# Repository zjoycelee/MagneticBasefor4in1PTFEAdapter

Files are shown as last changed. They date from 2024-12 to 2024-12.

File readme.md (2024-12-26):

# Bambulab 4-in-1 Adapter Holder with Magnetic Mount

This project provides 3D models for a **Bambulab 4-in-1 Adapter Holder** designed for easy attachment to the backplate of the **Bambu P1S/X1 3D printers**. The holder uses magnets for quick attachment and detachment, offering flexibility to easily move and adjust the adapter.

## Features

- **Magnetic Mount**: The holder uses magnets to attach securely to the backplate of the Bambu P1S/X1 3D printers.
- **Easy to Move and Adjust**: The magnetic attachment allows for simple repositioning of the adapter holder without the need for additional tools.
- **Space-saving**: The holder ensures the 4-in-1 adapter stays close to the backplate, minimizing clutter and maximizing space on your 3D printer.

## Advantages

- **Flexible Adjustment**: The magnetic mount makes it easy to reposition the adapter holder, giving you full control over the placement and ensuring it fits your workspace perfectly.
- **Convenient Movement**: Unlike fixed mounts, this solution allows you to move the adapter holder quickly and easily, without the hassle of screws or complicated installations.
- **Close Fit to the Backplate**: The design ensures that the adapter holder stays as close as possible to the backplate, optimizing space while maintaining a secure fit.

## Material Recommendation

Since the snap-fit is oriented along the Z-axis, it is recommended to use at least PETG material for 3D printing. Otherwise, the snap-fit may lack sufficient strength and may break easily. Based on testing, the following materials have been evaluated:

- [x] **Jayo PETG**: Suitable, with good strength; no issues with snap-fit durability.
- [ ] **Caige PLA**: Not suitable, with insufficient strength; prone to breaking.

## Folder Structure

This repository includes the following folder structure:

```bash
Copy code
assets/            # Folder for images (e.g., preview, magnet application)
stls/              # Folder for 3D model STL files
3mf/               # Folder for 3MF files
readme.md          # This README file
readme.zh.md       # readme in Chinese
.gitignore         # Git ignore file
```

## 3D Models

- The project includes 3D models for printing the adapter holder with a magnetic mount.
- You can find the **STL** and **3MF** files in the `stls/` and `3mf/` directories respectively.
- The holder is designed for easy integration with **Bambulab 4-in-1 Adapter**.

## Images

### Preview of the Adapter Holder
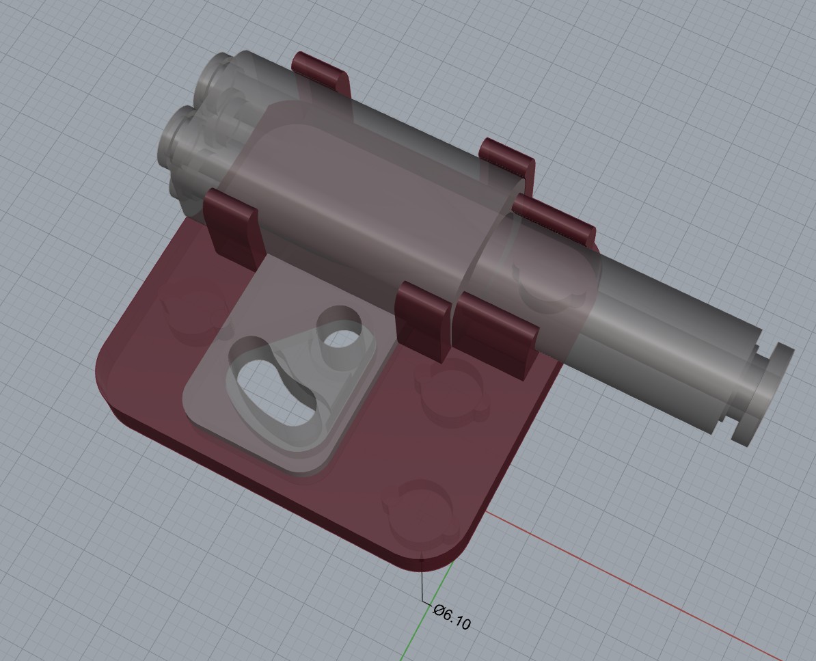
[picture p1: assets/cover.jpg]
Adapter Holder Preview

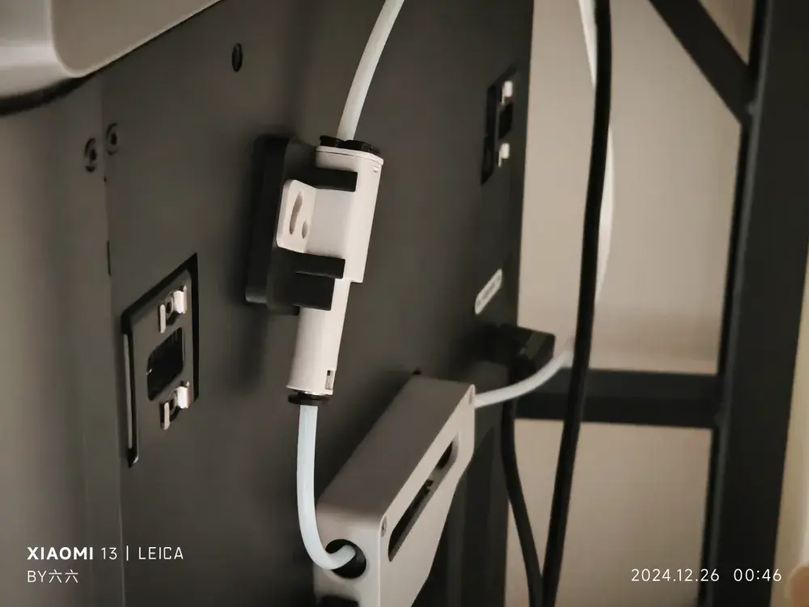
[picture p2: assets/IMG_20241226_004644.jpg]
live shot 1

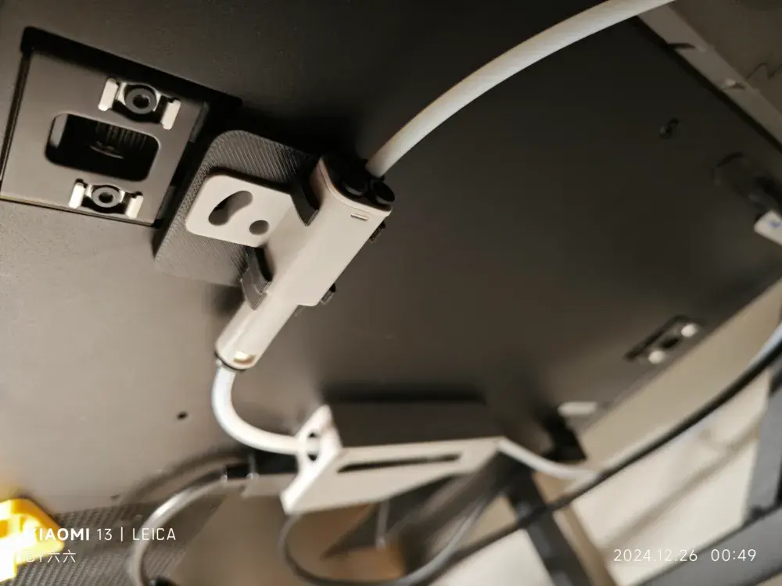
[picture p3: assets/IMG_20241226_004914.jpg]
live shot 2


Here is a preview of the **Bambulab 4-in-1 Adapter Holder** that you can print and use with your Bambu P1S/X1 3D printer.

### Magnet Application
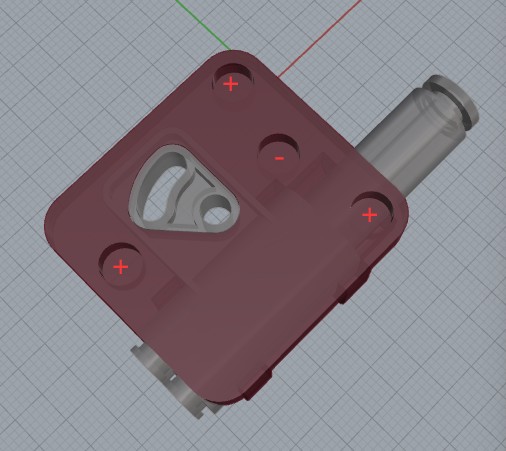
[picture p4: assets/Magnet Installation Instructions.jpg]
Magnet Application Introduction


This image demonstrates how to install the magnets to ensure the adapter holder is securely attached to the backplate of the Bambu P1S/X1 printer.

The hole size is D = 6.1mm and H = 3.4mm, while the magnet size is D = 6mm and H = 3mm. To ensure proper installation, the magnet should be aligned with the iron piece and pushed into the hole, ensuring that the surface of the magnet is flush with the surface of the model. This approach prevents the magnet from sinking too deep into the hole, which could lead to misalignment or improper magnetic performance.

## Assembly Instructions

1. **Print the Holder**: Download the 3D model files from the repository and print them using your 3D printer.
2. **Attach the Magnets**: Insert the magnets (D=6mm, H=3mm) into the designated holes on the holder.
3. **Mount on the Backplate**: Attach the magnetic holder to the backplate of your Bambu P1S/X1 printer. The magnets will hold the adapter securely in place.
4. **Adjust and Move**: You can now easily move and adjust the position of the adapter holder on the backplate for optimal space management.

## License

This project is licensed under the [Creative Commons Attribution 4.0 International License](https://creativecommons.org/licenses/by/4.0/).

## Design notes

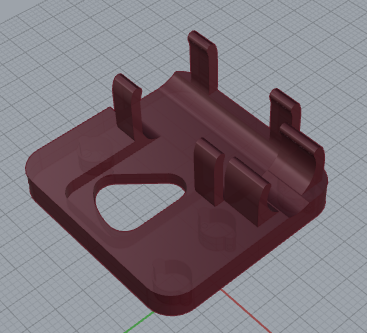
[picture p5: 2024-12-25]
assets/preview.png

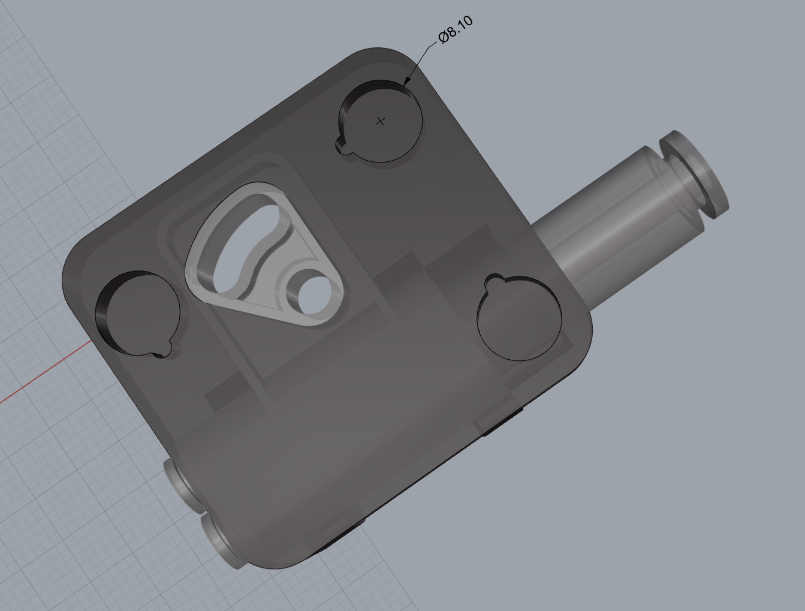
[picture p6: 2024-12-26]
assets/D8.1-H3.4.png

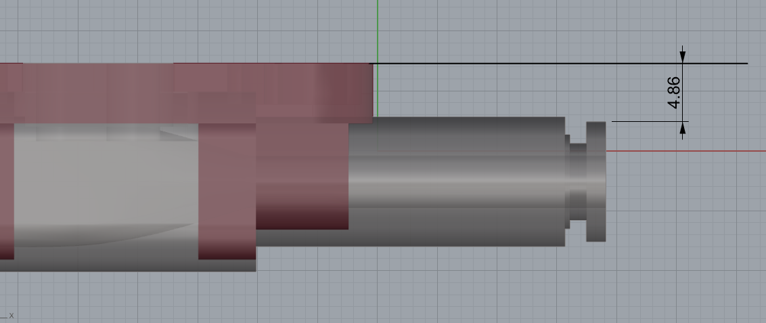
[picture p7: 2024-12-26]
assets/distance-introduction.png

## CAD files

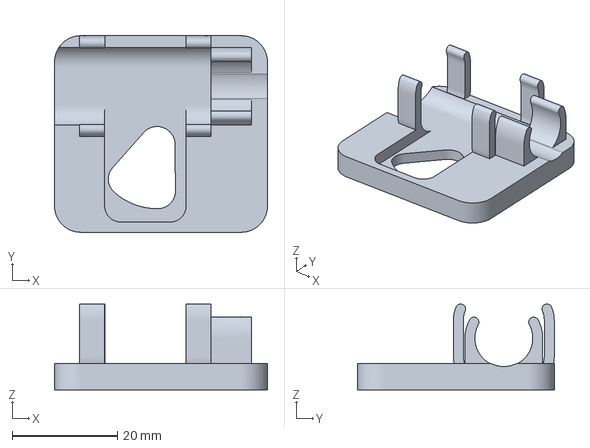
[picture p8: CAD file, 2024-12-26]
3mf/4-in-1-Adapter-Magnet-Holder(D8.1_H3.4).3mf
40.5 x 37.4 x 16.4 mm

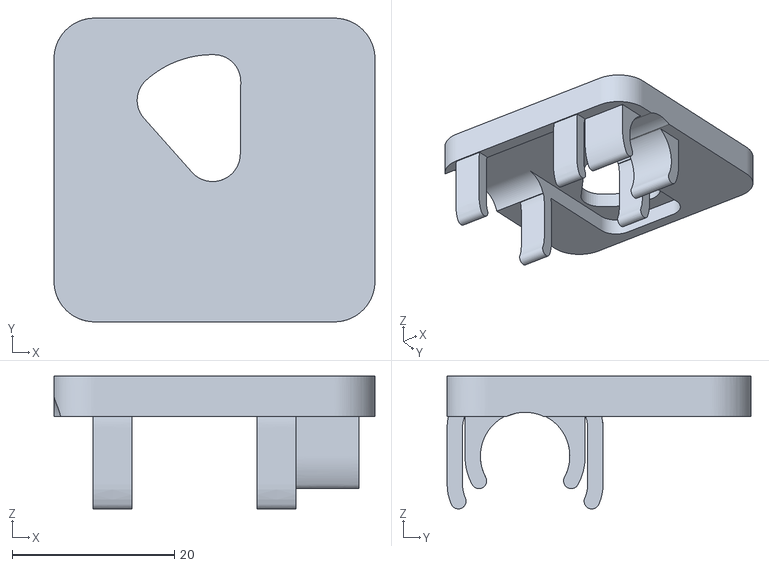
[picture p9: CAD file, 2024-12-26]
stls/withoutMagnetHoles.stl
39.5 x 37.4 x 16.4

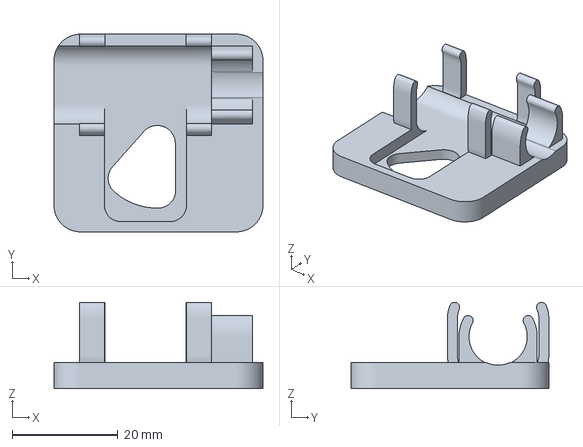
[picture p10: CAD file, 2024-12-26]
3mf/4-in-1-Adapter-Magnet-Holder(D6.1H3.4).3mf
39.5 x 37.4 x 16.4 mm

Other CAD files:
stls/D8.1H3.4.stl
stls/D6.1H3.4.stl

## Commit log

2024-12-25 add a holder(v2)
    [v2.stl]
2024-12-25 make circle bigger, d=2mm
    [v2.stl]
2024-12-25 add 3mf file
    [4-in-1-Adapter-Magnet-Holder.3mf]
2024-12-26 Add a new specification, D=8.1mm,H=3.4mm
    [D8.1H3.4.stl]
2024-12-26 chore: construct folder structure
    [D6.1H3.4.stl, D8.1H3.4.stl]
2024-12-26 feat: add 3mf file for D8H3.4 specification
    [4-in-1-Adapter-Magnet-Holder(D6.1H3.4).3mf, 4-in-1-Adapter-Magnet-Holder(D8.1_H3.4).3mf, 4-in-1-Adapter-Magnet-Holder.3mf]
2024-12-26 docs: update magnet application introduction
2024-12-26 docs: add material recommendation
2024-12-26 feat: Added new holder model without magnet inset hole, allowing for negative parts in ORCA to adapt to different magnet sizes.
    [withoutMagnetHoles.stl]
